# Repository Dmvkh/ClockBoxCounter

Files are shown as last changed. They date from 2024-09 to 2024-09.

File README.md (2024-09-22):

# ClockBoxCounter
'Arduino' based device which helps kids track scheduled tasks and chores progresses.

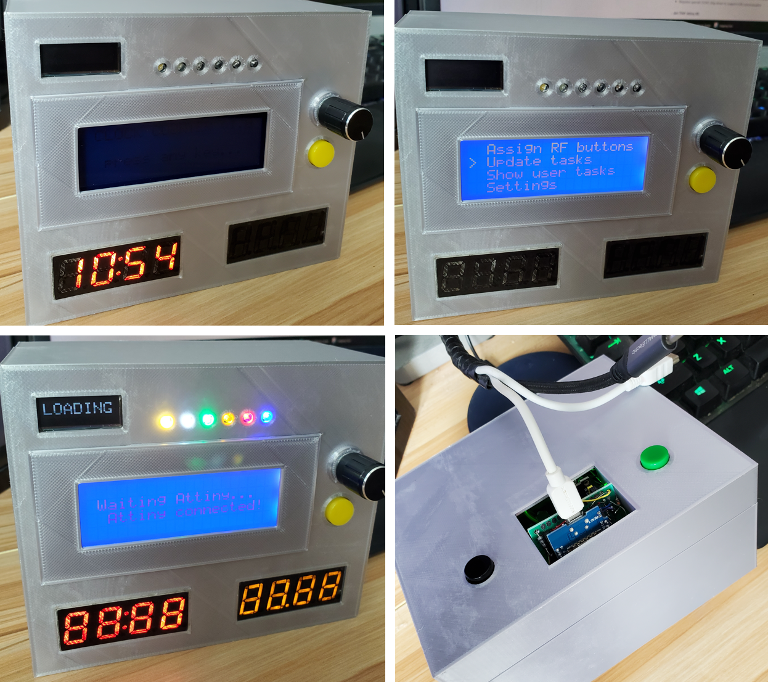
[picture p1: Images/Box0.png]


This device designed with 2 independent controllers in mind. Main controller (Wemos board) does Wi-Fi connections to maintain web-server API interactions and processes user actions.
Secondary controller (Attiny board) does async LED blinking, buzz sounds and reads some button inputs, without stuttering main board.

## Web Service:
 - Small LAN web-server @'Raspberry Pi'-like computer (Libre Computer Renegade), running Debian with Python-Dash (Flask) service and SQLite DB for containing existing user Tasks/Chores progresses and providing simple API interface for adding/updating users tasks.
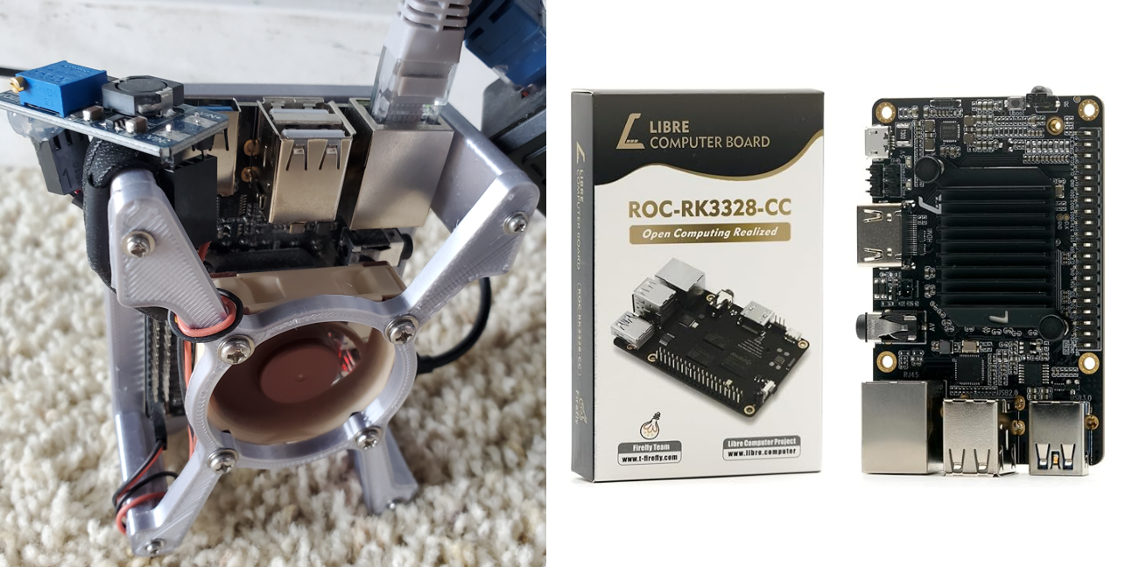
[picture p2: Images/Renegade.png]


## Used Electrical Parts:

### A) Controller Boards:

#### - Wemos D1 mini.
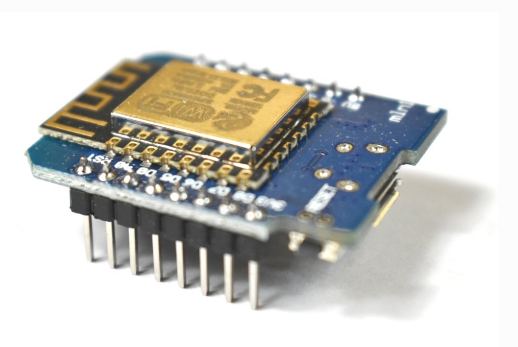
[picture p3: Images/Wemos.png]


Used as Master Controller. Interacts with web-server and controls user interface.

**Pros**

* Has integrated Esp8266 onboard to connect to Wi-Fi
* Interrupts on each digital pin
* Large sketch/variable memory
* Quick reboot time

**Cons**

* Small pins amount
* ESP architecture can't propely communicate with Attiny via I2C
* Analog pin can be used only as input
* Can't properly load and flash sketches if D8 pin is pulled-up
* Long compiling and flashing time, comparing to Attiny (up to 1 minute vs 10 secs)
* Randomly blocks virtual COM port after several flashes until PC is rebooted
* Requires special CH341 chip driver to support USB communication
  
#### - MH-TINY Attiny 88.
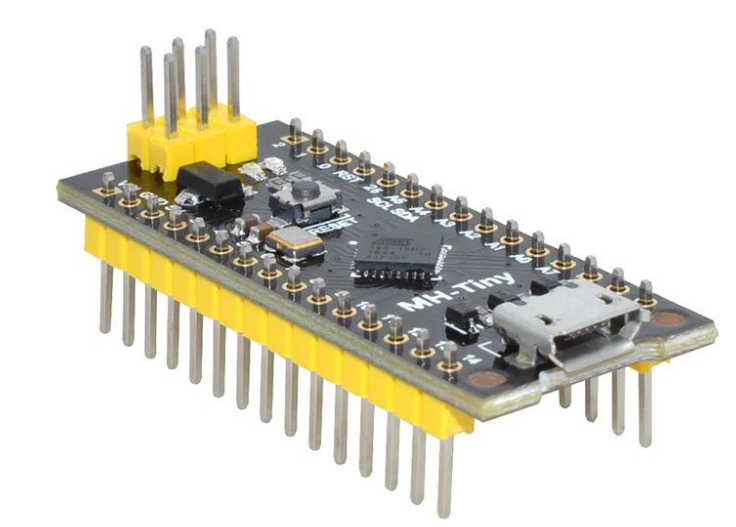
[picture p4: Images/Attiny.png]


Used as Slave Controller. Controls music and independent LEDs blinking.

**Pros**

* Very cheap alternative to Arduino
* Plenty of digital and analog PINs. Supports I2C

**Cons**

* **EXTREMELY** ! small RAM size for sketch and variables, which makes programming of many options very tricky
* Doesn't have hardware serial support, which makes it almost impossible to debug
* If variables use more than 96% of memory, became unstable
* For some reason can't communicate with ESP via I2C
* Long time to boot after reset (up to 8 seconds)

### B) Arduino components:

#### SSD1306 I2C OLED Display
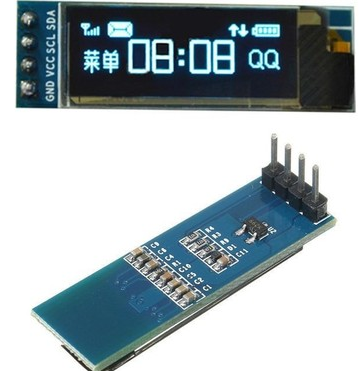
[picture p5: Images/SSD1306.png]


Used for short pop-up messages and progress bar visualisation.

#### 2004A I2C LCD 20 x 4 rows LCD Display
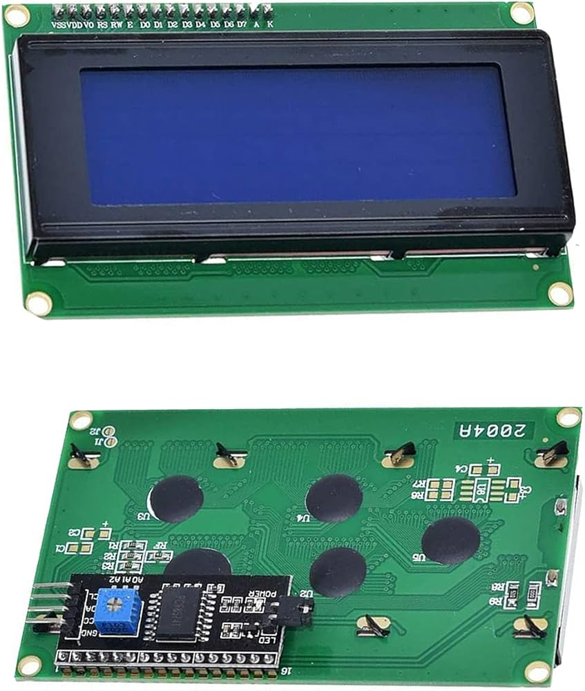
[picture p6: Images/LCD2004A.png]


Used for user menu and displaying text messages.

#### KY-040 Encoder
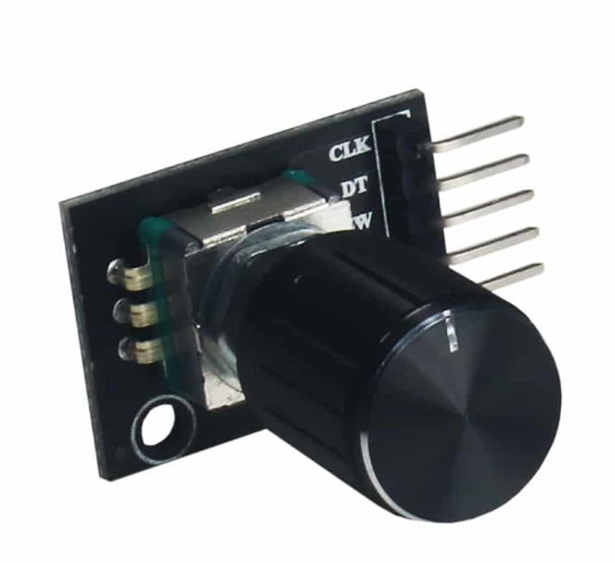
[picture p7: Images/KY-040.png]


Used for user iteraction with menu interface.

#### TM1637 4-digit 7-Segment LED Display (1x Clock-Type, 1x Decimal point type)
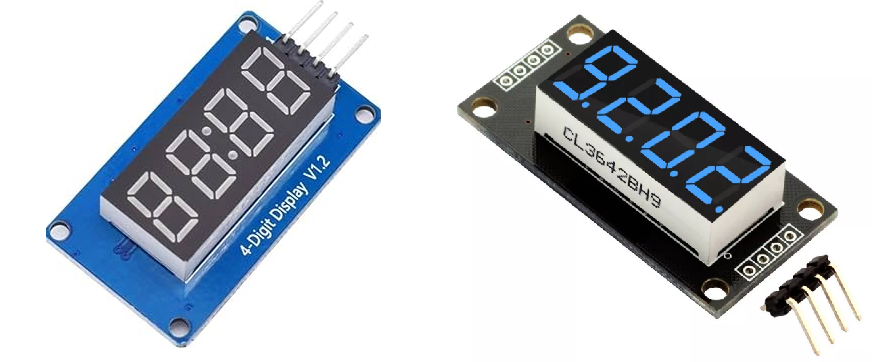
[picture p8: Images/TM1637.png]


Used for displaying clock in stand-by mode, and selected task progress in user-interaction mode.

#### RF 433 MHz Transmitter / Receiver modules
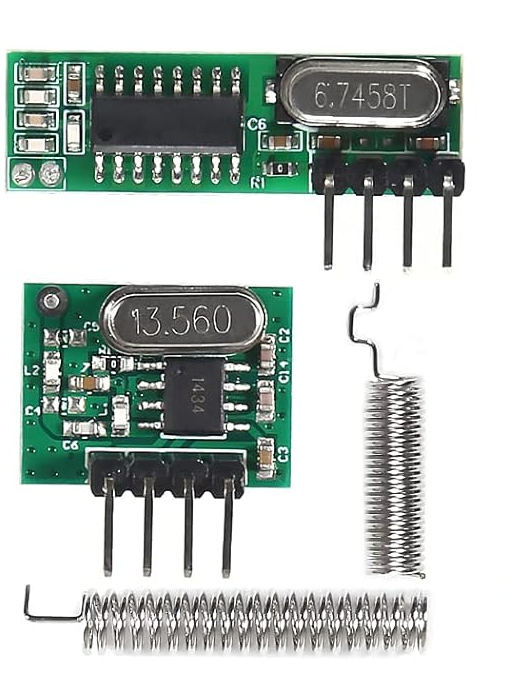
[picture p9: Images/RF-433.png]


Used for programming and reading pressed buttons of user remotes (for individual tasks display for each user).

#### User Remotes
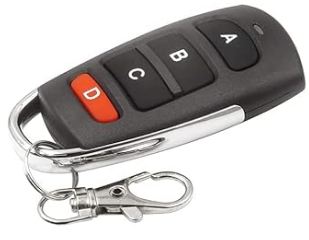
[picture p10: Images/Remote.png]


Programmable 433MHz remote used as individual console to interact with ClockBoxCounter.

#### Various small parts for Arduino

Push-up buttons, ultra-bright 3mm LEDs, breadboard, electronic components (diodes, resistors, capacitors, mosfet) for wiring circuit.

## Inner Wiring Scheme:



## Project progress:

### - Hardware progress

#### - Electronic
- [x] Schematic design
- [x] Components prototyping
- [x] Soldering circuit

#### - Hull Design
- [x] 3D model prototype fitting
- [x] Create case STL 3D model
- [ ] Add images with user-friendly wiring scheme **TODO**
- [ ] Add more photos and videos of finished device **TODO**

### - Software progress

#### - Attiny
- [x] Implement music (via buzzer)

  * Due to limited Attiny memory, async music play produced various crashes, hangs and memory overflows. Eventually I did it completely synchronous, which means that Attiny cannot blink or read pin signals until current melody is completed. Thus all melodies made as short as possible.
    
- [x] Implement LED blinking schemes
  - [x] Police blinking
  - [x] Individual LED blinking
- [x] Implement interactions with Master board
  
  * I hadn't been able to make I2C interation between Wemos and Attiny work (though, Wemos-Arduino Nano worked perfectly). Eventually, I changed I2C to Serial communication via SoftwareSerial on Attiny part (which severely limited available memory on Attiny board). Due to many componnents used in the circuit, UART communication may suffer from inducted noise. To mitigate that issue I experimented with baud rates and read delays and eventually implemented simple command checksum verification for communication protocol.
    
  - [x] Implement checksum verification to ensure proper command execution
- [x] Read push buttons and send signals to Master board

#### - Wemos
- [x] Implement Standby mode
- [x] Add Wi-Fi connection for internet and intranet data updates
- [x] Show clock in Standby mode
  - [x] Add clock sync with internet UTC service
- [x] Implement Attiny serial communication
  - [x] Add Attiny ping function to ensure that Slave board is online
- [ ] Add user menu interface **IN PROGRESS**
  - [x] Add placeholder screen for Standby mode (when backlight is off)
  - [x] Add menu interruption and resuming functions to show temporary messages
  - [x] Create Demo in Settings menu
  - [ ] Add ClockBox settings, stored in DB via API
- [x] Add LCD display text printing routine
- [x] Add OLED display text printing routine
  - [x] Add auto closing pop-up messages
  - [x] Add progress bar for long running processes  
- [x] Add user tasks dowloading via web-server API
   - [x] Add new tasks counter indicator in Standby mode
   - [x] Add task signals manifestatation (blinking/sounds) in Standby mode
   - [x] Add new tasks download from Web-server API
- [x] Implement RF 433 MHz protocol communication
  - [x] Add RF reading for detecting users and distinguish remote buttons pressed
  - [x] Add generating and transmitting RF signal for choosen user via Menu for remote programming
  - [x] Add interaction with downloaded tasks via RF remote

#### - LAN web server API
- [x] Add Web-Server API for individual user tasks
  - [x] Add tasks create/update interface for individual users

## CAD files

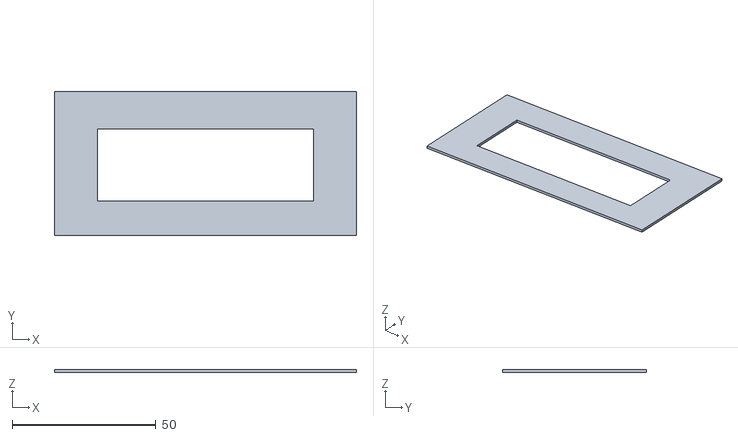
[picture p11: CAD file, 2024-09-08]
3D Printed/Counter_w.stl
105.0 x 50.0 x 1.00

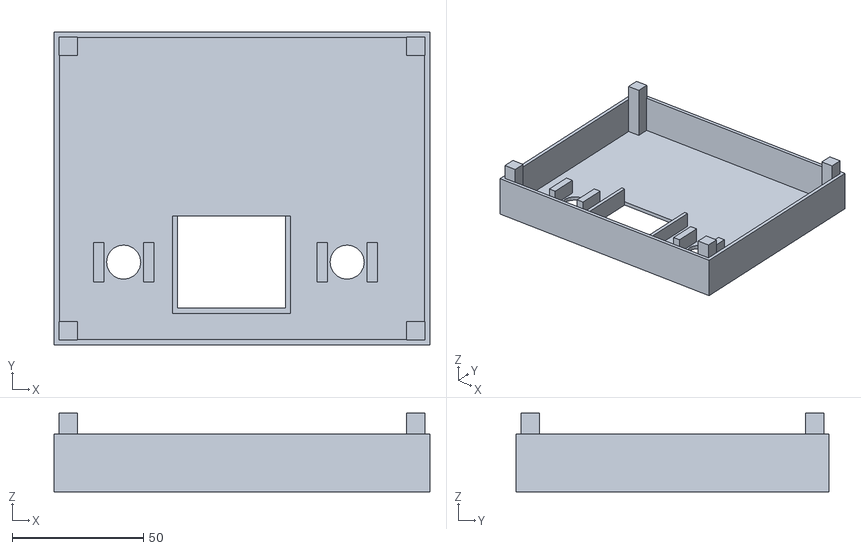
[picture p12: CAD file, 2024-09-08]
3D Printed/Counter_back.stl
143.0 x 119.0 x 30.0

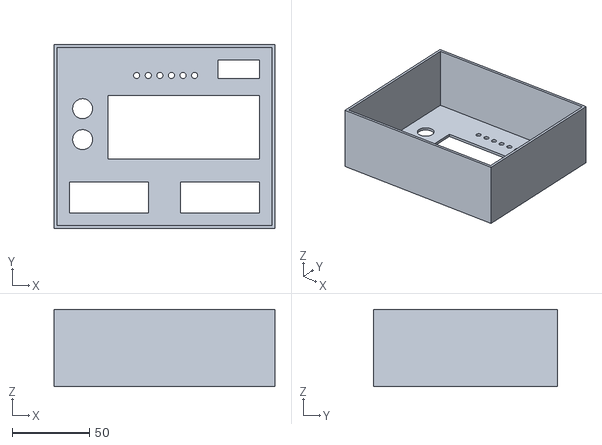
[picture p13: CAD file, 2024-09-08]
3D Printed/Counter.stl
143.0 x 119.0 x 50.0

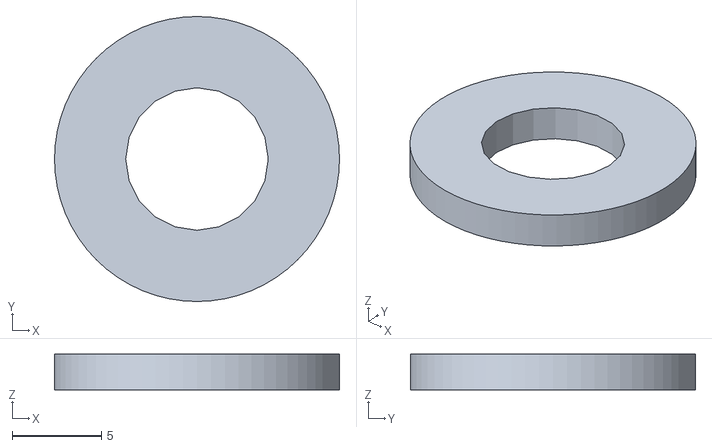
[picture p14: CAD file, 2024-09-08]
3D Printed/Counter_c.stl
16.0 x 16.0 x 2.00

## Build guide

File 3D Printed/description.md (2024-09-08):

3D-printed .stl models for ClockBoxCounter case.

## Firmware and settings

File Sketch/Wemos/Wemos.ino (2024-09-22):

#include <Wire.h>
#include <LiquidCrystal_I2C.h>
#include <Adafruit_SSD1306.h>
#include <TM1637.h>
#include <Encoder.h>
#include <RCSwitch.h>
#include <ESP8266HTTPClient.h>
#include <ESP8266WiFi.h>
#include <NTPClient.h>
#include <WiFiUdp.h>
#include <ArduinoJson.h>

// This file contains defines of sensitive credentials (marked with 'defined elsewhere' comment)
#include "Credentials.h"

#define OLED_SCREEN_WIDTH 128 // OLED display width, in pixels
#define OLED_SCREEN_HEIGHT 32 // OLED display height, in pixels
#define OLED_ADDR 0x3C

#define LCD_SCREEN_WIDTH 20 // OLED display width, in pixels
#define LCD_SCREEN_HEIGHT 4 // OLED display height, in pixels

#define USERS_TOTAL 4

const byte wheel_press = A0;

// UTC time offset, defined elsewhere
const long utcOffsetInSeconds = UTC_TIME_OFFSET;

LiquidCrystal_I2C lcd(0x27,20,4);

RCSwitch radioSwitch = RCSwitch();

HTTPClient http;
WiFiUDP ntpUDP;
WiFiClient client;
NTPClient timeClient(ntpUDP, "pool.ntp.org", utcOffsetInSeconds);

Adafruit_SSD1306 oled(OLED_SCREEN_WIDTH, OLED_SCREEN_HEIGHT);

TM1637 counter_clock(D0, D4);
TM1637 counter_number(D0, D3);

//instead of changing here, rather change numbers above
Encoder rotaryEncoder(D7, D8);

// Global consts
enum TimeWatch
{
     TimeWatch_Clock, // 0
     TimeWatch_WiFiTaskUpdate,
     TimeWatch_WiFiConnect,
     TimeWatch_StandBy,
     TimeWatch_ScheduledStandBy,
     TimeWatch_MenuInterrupt,
     TimeWatch_AttinyPing,
     TimeWatch_OLEDScroll,
     TimeWatch_OLEDProgressUpdate,
     TimeWatch_OLEDPrintErase,
     TimeWatch_CancelBtnPress,
     TimeWatch_Demo,
     TimeWatch_TaskAlertSound,
     TimeWatch_ActivityDataUpdate,
     WatchersCount,
};

const char SET_LEDS_MODE = '1';
const char SET_BLINK_MODE = '2';
const char SET_BUZZER_PLAY = '3';
const char SET_BTN1_PRESS = '4';
const char SET_SEND_MSG = '5';
const char PING_ATTINY_SIG = '6';
const char CHECKSUM_CONFIRM = '7';
const char PLAY_CUSTOM_TONE = '8';

const char BUZZER_CLICK = '1';
const char BUZZER_OK = '2';
const char BUZZER_ERROR = '3';
const char BUZZER_ALARM_1 = '4';
const char BUZZER_ALARM_2 = '5';
const char BUZZER_SMALL_BEEP = '6';
const char BUZZER_START_MELODY = '7';

const byte BLINK_BLUE = 0;
const byte BLINK_RED = 1;
const byte BLINK_YELLOW = 2;
const byte BLINK_GREEN = 3;
const byte BLINK_WHITE = 4;
const byte BLINK_ORANGE = 5;
const byte BLINK_POLICE = 6;

// Function prototypes with optional parameters
void OLED_PrintText(const char* text = NULL, byte textSize = 3, byte brightness = 50, byte eraseAfterSec = 5);
void SetLeds(byte leds_state = 0);
void LCD_WriteString(const char* text, byte xi, byte yi, bool updateLed = true, bool clearLineLeftover = false);
void PlaySound(char sound = BUZZER_CLICK);
bool IsTriggerTime(TimeWatch watcher, unsigned long currentMillis, unsigned int tickInterval, bool triggerOnInit = false, bool updateTimeOnTrigger = true);
void LCD_ScrollText(const char* text, bool continueScroll = true);
void SetBlinking(byte blink_mode, int blinkSpeed, byte blinkLimit = 255,  byte offTimesLonger = 10);

void DrawMenuOptions(byte optionsSize, char options[255][LCD_SCREEN_WIDTH - 2], byte activeItem);
void GetUserTasksList(byte user_id, byte& optionsSize, bool listActiveTasks, char options[255][LCD_SCREEN_WIDTH - 2]);
void UpdateTasksState(unsigned long currentMillis, bool forceTaskStateUpdate = false);

void setup() {
  
    Wire.begin();
    Serial.begin(9600);
    
    pinMode(wheel_press, INPUT);
    
    lcd.init();
    lcd.blink_off();
    lcd.cursor_off();
    lcd.clear();
    lcd.noBacklight();
    
    oled.begin(SSD1306_SWITCHCAPVCC, OLED_ADDR);
    
    oled.setTextWrap(false);
    oled.setTextColor(WHITE);
    OLED_Clear();    

    WiFi.mode(WIFI_STA);
    UpdateUserTasks();
    
    OLED_PrintText("LOADING");
    
    counter_clock.begin();
    counter_clock.setBrightnessPercent(80);
    
    counter_number.begin();
    counter_number.setBrightnessPercent(80);
    
    counter_clock.display(88.88);
    counter_number.display(88.88);

    lcd.backlight();
      
    InitEncoder();

    // Wait until Attiny is on
    while (!PingAttiny(false))
    {
    } 

    //PlaySound(BUZZER_START_MELODY);
    
    SetLeds(255); 
    
    counter_clock.clearScreen();
    counter_number.clearScreen();
    
    SetLeds();

    if (IsConnectingToWiFi())
    {
        ShowConnectLogo();
    }
    
    radioSwitch.enableTransmit(D6);
    radioSwitch.enableReceive(D5);
    radioSwitch.resetAvailable();
}

void loop() {
    unsigned long currentMillis =  millis();

    LCD_CheckStandBy(currentMillis);

    CheckOledPrintingState(currentMillis);
  
    ListenUIInteractions(currentMillis);    

    CheckMenuInterruption(currentMillis);
    
    ReadRadioSignal();
    
    ListenSerial();

    ShowClock(currentMillis);

    UpdateUserTasks();

    ProcessScheduler(currentMillis);
}

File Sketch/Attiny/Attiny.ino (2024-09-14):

#include <SoftwareSerial.h>

// SLC = A4
// SDA = A5

const byte led_Blue = 9;
const byte led_Red = 10;
const byte led_Yellow = 11;
const byte led_Green = 12;
const byte led_White = 13;
const byte led_Orange = 14;

const byte pin_btn = 15;

const byte buzzer = 8;

SoftwareSerial portOne(3, 4); // software serial #1: TX = digital pin 3, RX = digital pin 4

// Global vars
const char SET_LEDS_MODE = '1';
const char SET_BLINK_MODE = '2';
const char SET_BUZZER_PLAY = '3';
const char SET_BTN1_PRESS = '4';
const char SET_SEND_MSG = '5';
const char PING_ATTINY_SIG = '6';
const char CHECKSUM_CONFIRM = '7';
const char PLAY_CUSTOM_TONE = '8';

void setup() {
    // pins setup
    pinMode(led_Blue, OUTPUT);
    pinMode(led_Red, OUTPUT);
    pinMode(led_Yellow, OUTPUT);
    pinMode(led_Green, OUTPUT);
    pinMode(led_White, OUTPUT);
    pinMode(led_Orange, OUTPUT);
  
    pinMode(buzzer, OUTPUT);
  
    pinMode(pin_btn, INPUT);
  
    // initialize
    portOne.begin(9600);
   
    AnounceStartup();
}

unsigned long pressMillis = 0;

byte currentMelody = 0;
byte melodyNote = 0;

void loop() {

    unsigned long currentMillis = millis();
    
    ReadSerial();
    DoBlinking(currentMillis);
    ProcessMelody(currentMillis);
  
    // Button 1 press detected
    if (digitalRead(pin_btn) == HIGH && (currentMillis < pressMillis || pressMillis + 500 < currentMillis))
    {
        pressMillis = currentMillis;
  
        char msg[1] = { '1' };
        SendMessage_Serial(SET_BTN1_PRESS, 1, msg);
    }
}

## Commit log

2024-09-10 Fixed some memory leak issues. Changed Serial.flush() with proper buffer clear.
    [Menu.ino, OLED_Display.ino, Serial.ino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]
2024-09-10 Fixed clocks format bug
    [Buzz.ino, Clock.ino, ESP8266.ino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]
2024-09-11 Async time triggers rework. Added demo mode.
    [Clock.ino, ESP8266.ino, LCD_Display.ino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]
2024-09-21 Small updates and fixes
    [ESP8266.ino, Menu.ino, Misc.ino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]
